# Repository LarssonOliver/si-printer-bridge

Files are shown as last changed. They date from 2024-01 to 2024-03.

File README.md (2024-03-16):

# si-printer-bridge

si-printer-bridge is a simple system that aims to reduce complexity and hassle when
using the [SPORTident](https://www.sportident.com/) timing system during 
orienteering practice sessions.

si-printer-bridge allows a reader station to be connected directly to a thermal 
printer without the use of an android phone with bluetooth or similar. The 
entire system may be powered using a conventional USB power bank.

## SPORTident Device Support

The system has been successfully verified with the following devices.

| **Readers** | **USB VID** | **USB PID** |
|---|---|---|
| BSM 8-USB | `0x10C4` | `0x800A` |

| **Printers** | **USB VID** | **USB PID** |
|---|---|---|
| Miniprinter | `0x0416` | `0x5011` |

As for cards, they *should* all work. Validated ones are listed here.

| **Card Model** | **Validated Working** |
| --- | --- |
| SI-Card 5 | :heavy_check_mark: |
| SI-Card 6 | |
| SI-Card 8 | |
| SI-Card 9 | |
| SI-Card 10 | :heavy_check_mark: |
| SI-Card 11 | |
| SI pCard | |

## Materials

Here is a list of materials used to create a si-printer-bridge.

| **Component** | **Qty** | **Note** |
|---|---|---|
| Raspberry PI Pico | 1 | Can be W variant |
| Green LED Diode | 1 | 5mm diameter |
| Yellow LED Diode | 1 | 5mm diameter |
| USB-A female breakout | 2 | |
| Breakout board USB-C | 1 | [Polulu 3411](https://www.pololu.com/product/3411) |
| 220Ω Resistor | 4 | |

## Updating Device Firmware

See [the updating-firmware.md](./docs/updating-firmware.md) document for 
update instructions.

## Circuit Diagram

<p align="center">
  Circuit Diagram
</p>

## Assembled Unit

<p align="center">
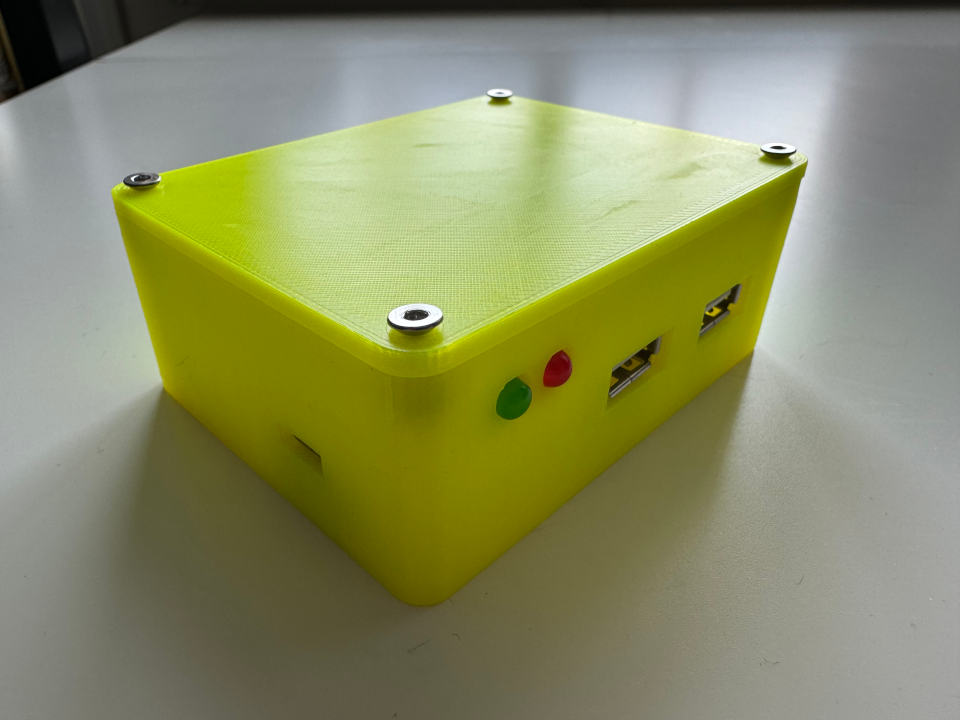
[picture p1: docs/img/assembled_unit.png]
Assembled Unit
  
</p>

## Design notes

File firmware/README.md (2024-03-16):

# si-printer-bridge Firmware

Firmware written in C built for the Raspberry Pi Pico.

Much of the reverse engineering is based on
[sportident-python](https://github.com/per-magnusson/sportident-python), which
is licensed under the GPL-3.0 license. You should have received a copy of the
GNU General Public License along with this program. If not, see
<[http://www.gnu.org/licenses/](http://www.gnu.org/licenses/)>.

All reimplementation of sportident-python may be found in the
[sportident](./src/sportident/) directory.

## Submodules

This firmware has a number of dependencies, linked as git submoduels
in the [./vendor](./vendor/) directory.

```bash
$ tree vendor -d -L 1
vendor
├── Pico-PIO-USB
├── pico-sdk
└── tinyusb
```

To get the submodules after a fresh clone, use:
```bash
git submodule update --init
```

## Compile

To compile a custom version, install the Arm GNU tool chain.
Append the Arm `bin` directory to the `PATH` environment variable.
The firmware can then be prepared and compiled with:

```bash
cmake -B build
cmake --build build
```

## Install

Hold the `BOOTSEL` button pressed on the Pico while plugging in the USB cable.
It should show up as a USB storage device. Drag-and-drop the `uf2` binary from
the build directory onto the device. The Pico should automatically restart and
run the firmware.

Alternatively, install `picotool` and run:

```bash
picotool load build/si-printer-bridge.uf2 --force
picotool reboot
```

## Clangd Language Server Config

To ensure clangd can see the Arm toolchain, update [.clangd](./.clangd) with
the appropriate path to ensure full LSP server support.

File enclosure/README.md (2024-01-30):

# Enclosure Model Files

OpenSCAD model files.

## Render

<p align="center">
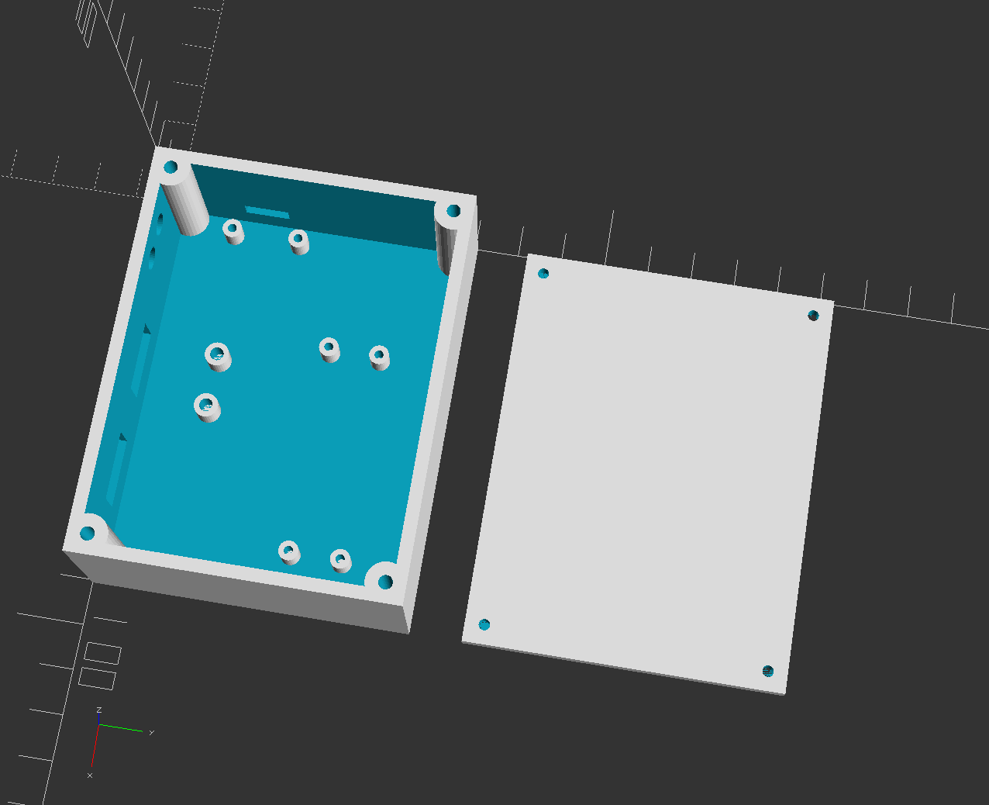
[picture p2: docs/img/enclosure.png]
Rendered image of enclosure.
  
</p>

## Render With Placeholder Components

<p align="center">
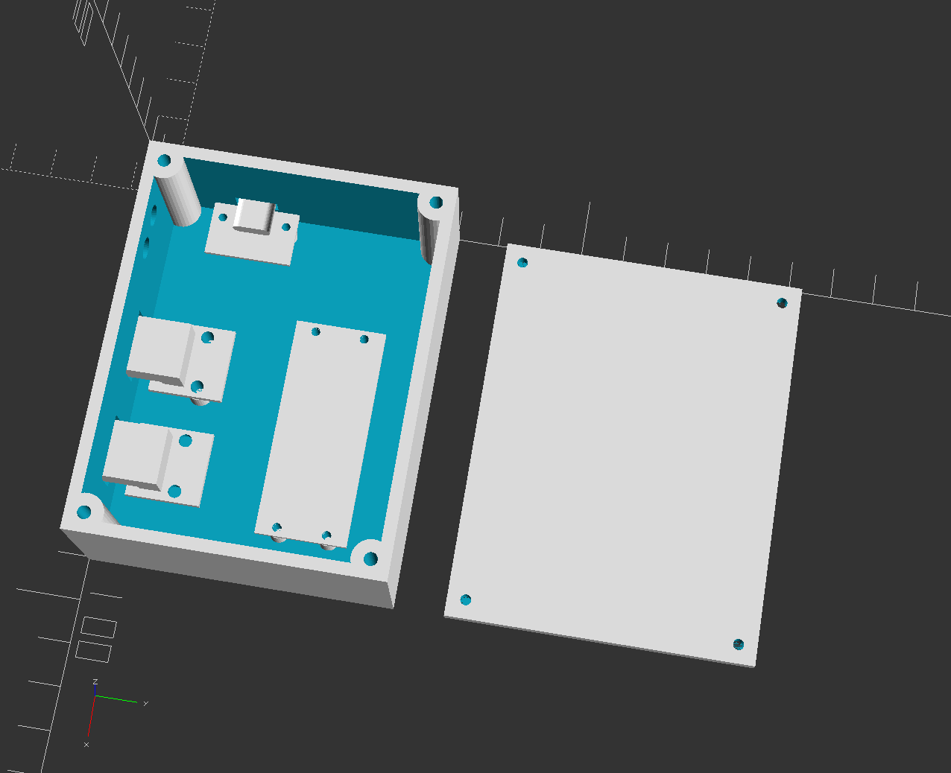
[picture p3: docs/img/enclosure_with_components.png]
Rendered image of enclosure.
  
</p>

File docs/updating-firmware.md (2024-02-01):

# Updating the Microcontroller Firmware

These instructions describe the process of loading a new firmware (in `.uf2` 
format) onto the Raspberry PI Pico microcontroller (RP2040).

Find the BOOTSEL button on the Pico microcontroller.

Illustration of Pico and BOOTSEL button

**NOTE:** Do not power the Pico using any external power source (such as a 
USB powerbank) during this procedure.

Depress the BOOTSEL button while plugging the microcontroller into a computer
using the micro-USB port on the short end of the Pico.

This makes the Pico show up as a drive in the operating system. Drag and 
drop the `.uf2` firmware file onto the drive.

Unplug the microcontroller.

The firmware is now updated and the device may be started as normal.

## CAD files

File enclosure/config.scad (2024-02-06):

/**
 * Copyright (C) 2024 Oliver Larsson
 *
 * This file is part of si-printer-bridge.
 *
 * si-printer-bridge is free software: you can redistribute it and/or modify it under
 * the terms of the GNU General Public License as published by the Free Software
 * Foundation, either version 3 of the License, or (at your option) any later
 * version.
 *
 * si-printer-bridge is distributed in the hope that it will be useful, but WITHOUT ANY
 * WARRANTY; without even the implied warranty of MERCHANTABILITY or FITNESS FOR
 * A PARTICULAR PURPOSE. See the GNU General Public License for more details.
 *
 * You should have received a copy of the GNU General Public License along with
 * si-printer-bridge. If not, see <https://www.gnu.org/licenses/>.
 */

WALL_THICKNESS = 2.8;
CORNER_INSET_SIZE = 4.0;
CORNER_SCREW_HOLE_SIZE = 3.4;

STANDOFF_HEIGHT = 7;

// Internal dimensions
INTERNAL_WIDTH = 85;
INTERNAL_DEPTH = 65;
INTERNAL_HEIGHT = 30;

// .1 mm tolerance
LED_DIODE_DIAMETER = 5.1;

SHOW_COMPONENTS = false;

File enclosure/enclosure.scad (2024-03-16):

/**
 * Copyright (C) 2024 Oliver Larsson
 *
 * This file is part of si-printer-bridge.
 *
 * si-printer-bridge is free software: you can redistribute it and/or modify it under
 * the terms of the GNU General Public License as published by the Free Software
 * Foundation, either version 3 of the License, or (at your option) any later
 * version.
 *
 * si-printer-bridge is distributed in the hope that it will be useful, but WITHOUT ANY
 * WARRANTY; without even the implied warranty of MERCHANTABILITY or FITNESS FOR
 * A PARTICULAR PURPOSE. See the GNU General Public License for more details.
 *
 * You should have received a copy of the GNU General Public License along with
 * si-printer-bridge. If not, see <https://www.gnu.org/licenses/>.
 */

include <config.scad>

use <modules/rpi_pico.scad>
use <modules/usb_a_female_pcb.scad>
use <modules/usb_c_female_pcb.scad>

module box()
{
    difference()
    {
        translate([ -WALL_THICKNESS, -WALL_THICKNESS, -WALL_THICKNESS ]) union()
        {
            translate([ 0, WALL_THICKNESS + CORNER_INSET_SIZE / 2, 0 ]) cube([
                INTERNAL_WIDTH + 2 * WALL_THICKNESS, INTERNAL_DEPTH - CORNER_INSET_SIZE, INTERNAL_HEIGHT +
                WALL_THICKNESS
            ]);
            translate([ WALL_THICKNESS + CORNER_INSET_SIZE / 2, 0, 0 ]) cube([
                INTERNAL_WIDTH - CORNER_INSET_SIZE, INTERNAL_DEPTH + 2 * WALL_THICKNESS, INTERNAL_HEIGHT +
                WALL_THICKNESS
            ]);
        };
        cube([ INTERNAL_WIDTH, INTERNAL_DEPTH, INTERNAL_HEIGHT + .1 ]);

        // Component cutouts
        translate([ INTERNAL_WIDTH - 20, -2, STANDOFF_HEIGHT ]) usb_a_cutout();
        translate([ INTERNAL_WIDTH - 45, -2, STANDOFF_HEIGHT ]) usb_a_cutout();
        translate([ -.5, 20, STANDOFF_HEIGHT ]) rotate(90, [ 0, 0, -1 ]) usb_c_cutout();

        // LED cutouts
        translate([ 12, .5, INTERNAL_HEIGHT - 8 ]) rotate(90, [ 1, 0, 0 ])
            cylinder(d = LED_DIODE_DIAMETER + .15, h = WALL_THICKNESS + 1, $fn = 32);
        translate([ 20, .5, INTERNAL_HEIGHT - 8 ]) rotate(90, [ 1, 0, 0 ])
            cylinder(d = LED_DIODE_DIAMETER + .15, h = WALL_THICKNESS + 1, $fn = 32);
    }

    // Corners
    translate([ CORNER_INSET_SIZE / 2, CORNER_INSET_SIZE / 2, -WALL_THICKNESS ]) difference()
    {
        cylinder(d = 2 * WALL_THICKNESS + CORNER_INSET_SIZE, h = INTERNAL_HEIGHT + WALL_THICKNESS, $fn = 32);
        translate([ 0, 0, WALL_THICKNESS ]) cylinder(d = CORNER_INSET_SIZE, h = INTERNAL_HEIGHT + 1, $fn = 32);
    }

    translate([ INTERNAL_WIDTH - CORNER_INSET_SIZE / 2, CORNER_INSET_SIZE / 2, -WALL_THICKNESS ]) difference()
    {
        cylinder(d = 2 * WALL_THICKNESS + CORNER_INSET_SIZE, h = INTERNAL_HEIGHT + WALL_THICKNESS, $fn = 32);
        translate([ 0, 0, WALL_THICKNESS ]) cylinder(d = CORNER_INSET_SIZE, h = INTERNAL_HEIGHT + 1, $fn = 32);
    }

    translate([ CORNER_INSET_SIZE / 2, INTERNAL_DEPTH - CORNER_INSET_SIZE / 2, -WALL_THICKNESS ]) difference()
    {
        cylinder(d = 2 * WALL_THICKNESS + CORNER_INSET_SIZE, h = INTERNAL_HEIGHT + WALL_THICKNESS, $fn = 32);
        translate([ 0, 0, WALL_THICKNESS ]) cylinder(d = CORNER_INSET_SIZE, h = INTERNAL_HEIGHT + 1, $fn = 32);
    }

    translate([ INTERNAL_WIDTH - CORNER_INSET_SIZE / 2, INTERNAL_DEPTH - CORNER_INSET_SIZE / 2, -WALL_THICKNESS ])
        difference()
    {
        cylinder(d = 2 * WALL_THICKNESS + CORNER_INSET_SIZE, h = INTERNAL_HEIGHT + WALL_THICKNESS, $fn = 32);
        translate([ 0, 0, WALL_THICKNESS ]) cylinder(d = CORNER_INSET_SIZE, h = INTERNAL_HEIGHT + 1, $fn = 32);
    }

    // Standoffs

    translate([ INTERNAL_WIDTH - 60, INTERNAL_DEPTH - 20, STANDOFF_HEIGHT ]) rotate(90, [ 0, 0, -1 ])
        rpi_pico_standoffs(height = STANDOFF_HEIGHT);

    translate([ INTERNAL_WIDTH - 20, -2, STANDOFF_HEIGHT ]) usb_a_standoffs(height = STANDOFF_HEIGHT);
    translate([ INTERNAL_WIDTH - 45, -2, STANDOFF_HEIGHT ]) usb_a_standoffs(height = STANDOFF_HEIGHT);
    translate([ -1, 20, STANDOFF_HEIGHT ]) rotate(90, [ 0, 0, -1 ]) usb_c_standoffs(height = STANDOFF_HEIGHT);
}

translate([ WALL_THICKNESS, WALL_THICKNESS, WALL_THICKNESS ]) box();

module lid()
{
    difference()
    {
        union()
        {
            translate([ CORNER_INSET_SIZE / 2, -WALL_THICKNESS, 0 ])
                cube([ INTERNAL_WIDTH - CORNER_INSET_SIZE, INTERNAL_DEPTH + 2 * WALL_THICKNESS, WALL_THICKNESS ]);
            translate([ -WALL_THICKNESS, CORNER_INSET_SIZE / 2, 0 ])
                cube([ INTERNAL_WIDTH + 2 * WALL_THICKNESS, INTERNAL_DEPTH - CORNER_INSET_SIZE, WALL_THICKNESS ]);

            translate([ CORNER_INSET_SIZE / 2, CORNER_INSET_SIZE / 2, 0 ])
                cylinder(d = 2 * WALL_THICKNESS + CORNER_INSET_SIZE, h = WALL_THICKNESS, $fn = 32);
            translate([ INTERNAL_WIDTH - CORNER_INSET_SIZE / 2, CORNER_INSET_SIZE / 2, 0 ])
                cylinder(d = 2 * WALL_THICKNESS + CORNER_INSET_SIZE, h = WALL_THICKNESS, $fn = 32);
            translate([ INTERNAL_WIDTH - CORNER_INSET_SIZE / 2, INTERNAL_DEPTH - CORNER_INSET_SIZE / 2, 0 ])
                cylinder(d = 2 * WALL_THICKNESS + CORNER_INSET_SIZE, h = WALL_THICKNESS, $fn = 32);
            translate([ CORNER_INSET_SIZE / 2, INTERNAL_DEPTH - CORNER_INSET_SIZE / 2, 0 ])
                cylinder(d = 2 * WALL_THICKNESS + CORNER_INSET_SIZE, h = WALL_THICKNESS, $fn = 32);
        };

        // Corners
        translate([ CORNER_INSET_SIZE / 2, CORNER_INSET_SIZE / 2, 0 ])
            cylinder(d = CORNER_SCREW_HOLE_SIZE, h = INTERNAL_HEIGHT + 1, $fn = 32);

        translate([ INTERNAL_WIDTH - CORNER_INSET_SIZE / 2, CORNER_INSET_SIZE / 2, 0 ])
            cylinder(d = CORNER_SCREW_HOLE_SIZE, h = INTERNAL_HEIGHT + 1, $fn = 32);

        translate([ CORNER_INSET_SIZE / 2, INTERNAL_DEPTH - CORNER_INSET_SIZE / 2, 0 ])
            cylinder(d = CORNER_SCREW_HOLE_SIZE, h = INTERNAL_HEIGHT + 1, $fn = 32);

        translate([ INTERNAL_WIDTH - CORNER_INSET_SIZE / 2, INTERNAL_DEPTH - CORNER_INSET_SIZE / 2, 0 ])
            cylinder(d = CORNER_SCREW_HOLE_SIZE, h = INTERNAL_HEIGHT + 1, $fn = 32);
    }
}

translate([ WALL_THICKNESS, INTERNAL_DEPTH + 20, 0 ]) lid();

if (SHOW_COMPONENTS)
{
    translate([ WALL_THICKNESS, WALL_THICKNESS, WALL_THICKNESS ])
    {
        translate([ INTERNAL_WIDTH - 60, INTERNAL_DEPTH - 20, STANDOFF_HEIGHT ]) rotate(90, [ 0, 0, -1 ]) rpi_pico();

        translate([ INTERNAL_WIDTH - 20, -2, STANDOFF_HEIGHT ]) usb_a_female_pcb();
        translate([ INTERNAL_WIDTH - 45, -2, STANDOFF_HEIGHT ]) usb_a_female_pcb();

        translate([ -1, 20, STANDOFF_HEIGHT ]) rotate(90, [ 0, 0, -1 ]) usb_c_female_pcb();
    }
}

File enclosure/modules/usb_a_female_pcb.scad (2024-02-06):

/**
 * Copyright (C) 2024 Oliver Larsson
 *
 * This file is part of si-printer-bridge.
 *
 * si-printer-bridge is free software: you can redistribute it and/or modify it under
 * the terms of the GNU General Public License as published by the Free Software
 * Foundation, either version 3 of the License, or (at your option) any later
 * version.
 *
 * si-printer-bridge is distributed in the hope that it will be useful, but WITHOUT ANY
 * WARRANTY; without even the implied warranty of MERCHANTABILITY or FITNESS FOR
 * A PARTICULAR PURPOSE. See the GNU General Public License for more details.
 *
 * You should have received a copy of the GNU General Public License along with
 * si-printer-bridge. If not, see <https://www.gnu.org/licenses/>.
 */

// This module is a model of
// https://www.electrokit.com/en/product/usb-b-hona-monterad-pa-kort/
module usb_a_female_pcb()
{
    // PCB
    PCB_THICKNESS = 1.6;
    PCB_WIDTH = 17.0;
    PCB_DEPTH = 17.0;
    PCB_Y_OFFSET = 6.0;
    PCB_HOLE_DIAMETER = 3.0;
    PCB_HOLE_DISTANCE = 12.0;
    PCB_HOLE_Y_OFFSET = 11.0;

    translate([ 0, 0, PCB_THICKNESS ])
    {
        difference()
        {
            translate([ -(PCB_WIDTH / 2), PCB_Y_OFFSET, -PCB_THICKNESS ]) cube([ PCB_WIDTH, PCB_DEPTH, PCB_THICKNESS ]);
            translate([ PCB_HOLE_DISTANCE / 2, PCB_Y_OFFSET + PCB_HOLE_Y_OFFSET, -(PCB_THICKNESS + .5) ])
                cylinder(d = PCB_HOLE_DIAMETER, h = PCB_THICKNESS + 1, $fn = 32);
            translate([ -PCB_HOLE_DISTANCE / 2, PCB_Y_OFFSET + PCB_HOLE_Y_OFFSET, -(PCB_THICKNESS + .5) ])
                cylinder(d = PCB_HOLE_DIAMETER, h = PCB_THICKNESS + 1, $fn = 32);
        }

        translate([ -13.1 / 2, 14 - 5, 0 ]) cube([ 13.1, 5, 7 ]);
        translate([ -13.1 / 2, 14 - 5, 0 ]) cube([ 13.1, 5, 7 ]);

        difference()
        {
            translate([ -13.1 / 2, 0, 7 - 5.75 ]) cube([ 13.1, 14, 5.75 ]);
            translate([ -12.5 / 2, -.1, 7 - 5.75 + (5.75 - 5.1) / 2 ]) cube([ 12.5, 10.1, 5.1 ]);
        }
    }
};

module usb_a_standoffs(inset_diameter = 4.0, wall_thickness = 1.6, height = 5)
{
    PCB_Y_OFFSET = 6.0;
    PCB_HOLE_DISTANCE = 12.0;
    PCB_HOLE_Y_OFFSET = 11.0;

    translate([ PCB_HOLE_DISTANCE / 2, PCB_Y_OFFSET + PCB_HOLE_Y_OFFSET, 0 ]) difference()
    {
        translate([ 0, 0, -height ]) cylinder(d = inset_diameter + 2 * wall_thickness, h = height, $fn = 32);
        translate([ 0, 0, -(height + .5) ]) cylinder(d = inset_diameter, h = height + 1, $fn = 32);
    }
    translate([ -PCB_HOLE_DISTANCE / 2, PCB_Y_OFFSET + PCB_HOLE_Y_OFFSET, 0 ]) difference()
    {
        translate([ 0, 0, -height ]) cylinder(d = inset_diameter + 2 * wall_thickness, h = height, $fn = 32);
        translate([ 0, 0, -(height + .5) ]) cylinder(d = inset_diameter, h = height + 1, $fn = 32);
    }
};

module usb_a_cutout(thickness = 10)
{
    translate([ -15 / 2, -thickness, 1.6 + .5 ]) cube([ 15, thickness + 4, 7.5 ]);
};

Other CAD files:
enclosure/modules/rpi_pico.scad
enclosure/modules/usb_c_female_pcb.scad

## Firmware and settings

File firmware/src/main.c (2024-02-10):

/**
 * Copyright (C) 2024 Oliver Larsson
 *
 * This file is part of si-printer-bridge.
 *
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
 * You should have received a copy of the GNU General Public License along with
 * si-printer-bridge. If not, see <https://www.gnu.org/licenses/>.
 */

#include <hardware/watchdog.h>
#include <pico/multicore.h>
#include <pico/stdlib.h>
#include <pico/time.h>
#include <tusb.h>

#include "console.h"
#include "data_processor.h"
#include "devices.h"
#include "led.h"

// REF:
// https://github.dev/sekigon-gonnoc/Pico-PIO-USB/blob/main/examples/host_hid_to_device_cdc
// https://github.com/hathach/tinyusb/blob/master/examples/host/cdc_msc_hid/src/main.c

// TODO: Watchdog stuff.
// TODO: Check if station is in readout mode on connect.
// TODO: Check if connected usb device is a (correct) SI station.
// TODO: Check that station is in extended command mode.
// TODO: Check BAUD rates?

void core1_main(void) {
  sleep_ms(10);

  watchdog_enable(1000, true);

  devices_init();
  devices_register_input_callback(on_data_received);

  bool second_init = false;

  while (true) {
    // This core does most of the work.
    watchdog_update();

    devices_tick();

    if (!second_init) {
      absolute_time_t time = get_absolute_time();
      if (to_ms_since_boot(time) > 1000) {
        devices_init2();
        second_init = true;
      }
    }
  }
}

int main(void) {
  set_sys_clock_khz(120000, true);

  sleep_ms(10);

  multicore_reset_core1();
  multicore_launch_core1(core1_main);

  console_init();

  led_init();
  led_set(LED_POWER, true);

  while (true) {
    console_tick();

    if (!console_is_connected())
      sleep_ms(10);
  }

  return 0;
}

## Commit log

2024-01-06 Fixed usb config issue
    [usb.h]
2024-01-13 Start with printer driver
2024-01-14 First print success
2024-01-20 Two devices support
2024-01-20 Small refactor and error checking
    [usb.h]
2024-01-20 Now printing labels
2024-01-20 Printing formatting
2024-01-21 Printing works
2024-01-21 Circuit diagram
2024-01-22 Console sending threading
2024-01-24 📜 License disclaimers added to firmware source files.
2024-01-30 Openscad modeling started
    [config.scad, enclosure.scad, usb_a_female_pcb.scad]
2024-01-30 Usb C board
    [enclosure.scad, usb_c_female_pcb.scad]
2024-01-30 Initial enclosure model
    [config.scad, enclosure.scad, rpi_pico.scad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]
2024-01-30 Rendered enclosure images
2024-02-05 Update circuit diagram
2024-02-05 Make circuit svg white
2024-02-05 ✏ Rename project to si-printer-bridge
    [config.scad, enclosure.scad, rpi_pico.scad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]
2024-02-06 Enclosure rounded corners
    [config.scad, enclosure.scad]
2024-02-06 Enclosure hole sizes
    [config.scad, rpi_pico.scad, usb_a_female_pcb.scad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]
2024-02-06 LED Diode tolerance
    [config.scad]
2024-02-10 Power and status LED code
2024-03-16 📸 Image of assembled unit added
2024-03-16 🩹 Move USB C board closer to case wall
    [enclosure.scad]
2024-03-16 📝 Docs update
